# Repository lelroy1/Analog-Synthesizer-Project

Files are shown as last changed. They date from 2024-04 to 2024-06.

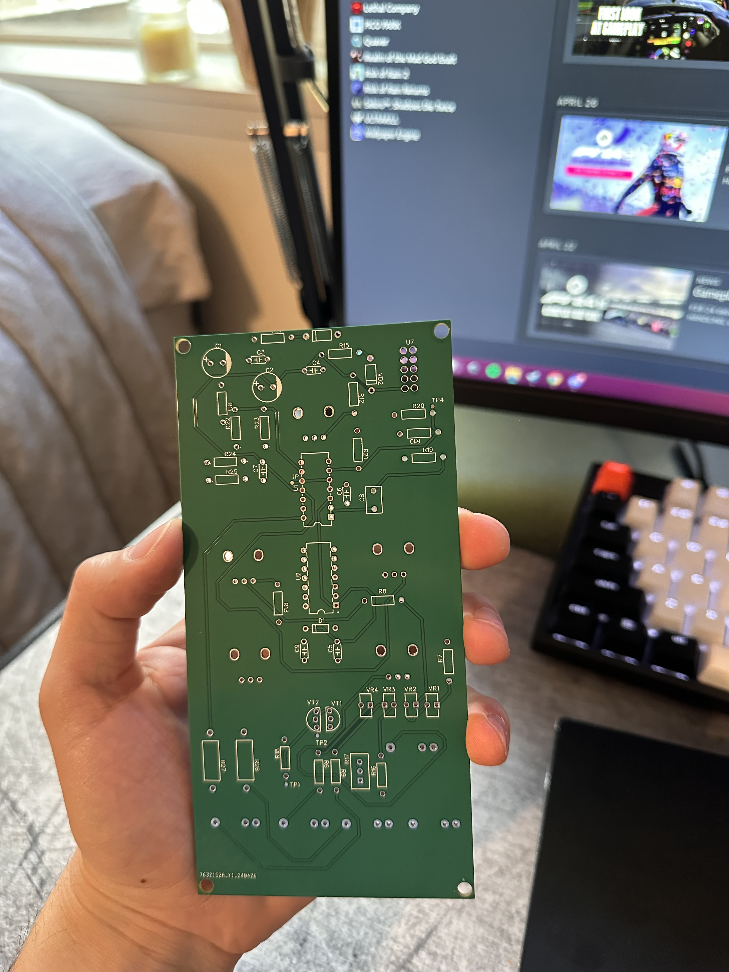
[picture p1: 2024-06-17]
VCO/PCB before Soldering back.JPG

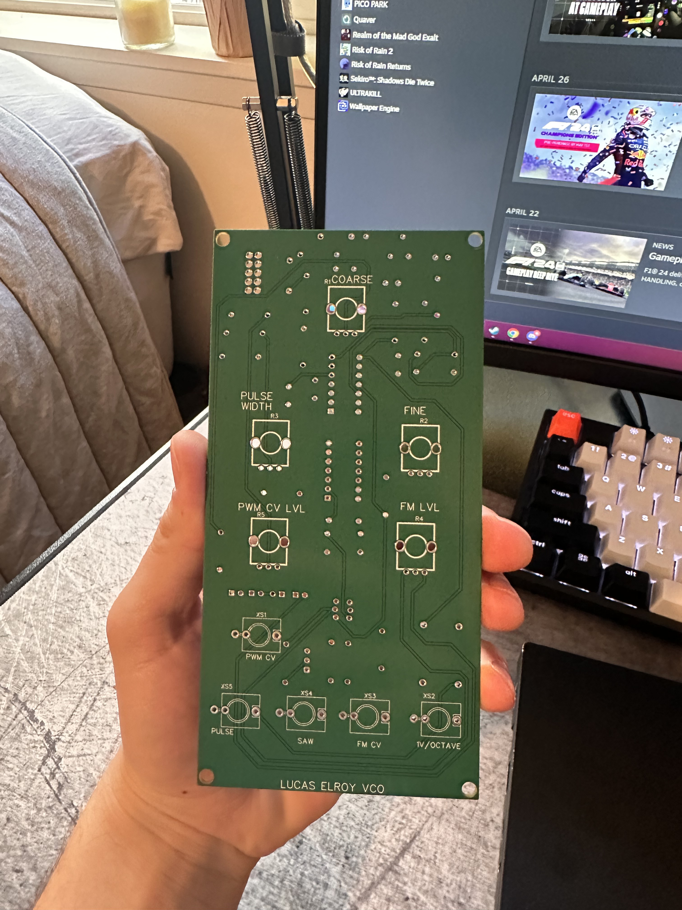
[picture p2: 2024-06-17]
VCO/PCB before Soldering.JPG

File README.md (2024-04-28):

# Analog-Synthesizer-Project
This repository contains all the work I've done to design my own analog synthesizer. The ultimate goal of this project is to design the analog circuits for a VCO (voltage controlled oscilator), VCA (voltage controlled amplifier) and VCF (voltage controlled filter). The design process for each of these components will be detailed here. The basic design flow will be testing and simulating in LTSpice, breadboarding the design, then creating a PCB. Along with this I will be machining cases each of these components and designing a power supply unit for them.

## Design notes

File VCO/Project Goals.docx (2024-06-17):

1. Understand the process of designing PCBs better.
  a. Sourcing correct parts for a design and what facets of a part are important aside from just component resistance/capacitance
  b. Where to place components for performance and correctness
2. Learn more about analog design
  a. Adding some sort of feature to the design
  b. Understanding each part of the design
3. Investigate a potential passion I may have (Music related Electrical Engineering)
  a. Analyze if this is something to continue pursuing after completion.

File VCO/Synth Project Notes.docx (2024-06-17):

4/6 - Today I did a basic creation of the schematic of the VCO. I’m worried about how to simulate it and I will likely need to go through and insert all the part numbers. I need to find these on a website to source all of them from. Make 100% sure everything matches.

Next Steps: Formulate some questions for Robert (peer reviewer) about simulating

4/7 - Today I redid the circuit by remodeling the components to spice models that way I can simulate it. Tomorrow I should look into actually simulating it which might require looking into those youtube videos a lot more so I understand what to test.

4/9 - I’m pretty stuck on simulating the reverse sawtooth oscillator core. I can’t figure out how to get the inverter to oscillate. Tomorrow you should look into downloading the CD40106 model onto LTspice and get it to actually work.

4/10 - I got the basic spice simulation working for the oscillator core. I also did some research into sourcing the parts for the PCB. I need to make sure Robert checks these. Tomorrow I will finish sourcing these parts and maybe look into simulating the whole circuit just to verifying I didn’t mess up routing.

4/11 - I need to find a way to put the 10 pin male connector on the PCB. I was also thinking that I need to spend significantly more time understanding the circuit I am creating. That way I learn more and get more confidence with the creation. There is also the idea of adding some sort of difference between my design and the mortiz klein one. Change capacitor footprint.

4/12 - Does the pin which is negative 12 matter vs positive 12 when it comes to plugging in the power supply? My guess is no.

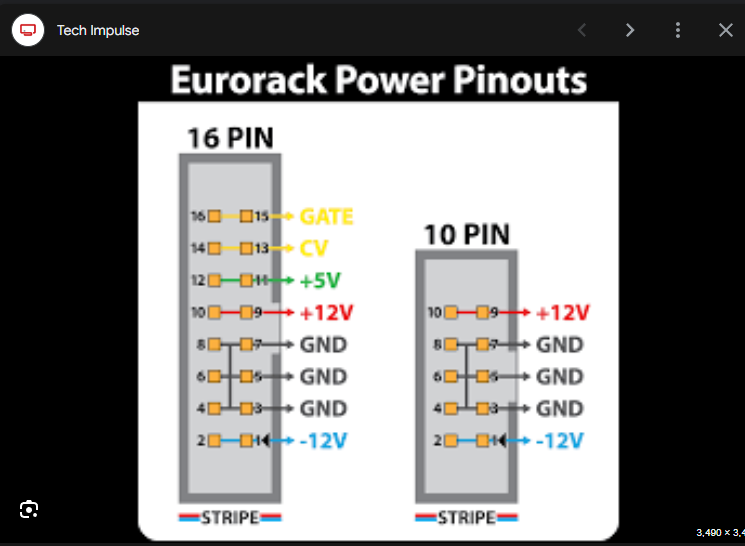
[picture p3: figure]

https://www.google.com/search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

4/14 - I spent some time today just understanding PCB design stuff and watching videos on it. I am torn about whether I want to go through and simulate the entirety of the design to better understand it. If I do choose to go down that route it will likely take up the next month of my time and I’m being lazy by not wanting to do that. So, let's discuss what my process should be. I like the idea of potentially building the circuit alongside the designs and testing each phase incrementally to understand the entirety of the circuit step by step. So I guess my next step now would be to model the voltage controlled resistor with the BJTs.

4/18 - Should I have both a +12V and -12V plane? Some pins on PCB have no lines referencing where they should be routed to is this do I route them to the correct reference anyway? Should I wire together all +12, -12, GND references on PSU 10 pin connector?

4/19 - route tp on top and bottom

4/21 -

- there needs to be a copper pour on the same layer as the traces, so you dont have large amounts of empty space. The manufacturer may have to leave it in the etch longer to make larger areas dissolve, though this isn't much of a problem in modern pcb manufacturing. you should make this a ground layer, and add test points to it on the outside, so that you can have many easy access points to ground when probing for testing. you can even buy test point clip parts. one we like is 5001 from keystone.

Currently having a problem with the DRC related to the ground holes in the corners.

4/23 - still having the problem with creating mounting holes. I’m also now concerned with the PSU. I did not realize it would be $80 so now I’m considering powering the whole system with 2 9 volt batteries or a bench power supply ~$50. For now I will just use the power supplies in the tectronics lab.

4/24 - currently in the process of simulating everything from the youtube videos.

4/28 - I need to go into the techtronics lab to breadboard and test the circuit.

VCO - voltage controlled oscillator.

Needs to be tuned with a pitch knob

This seems to be the basis of all oscillation in a synth. Here is the basic design of a sawtooth oscillator:

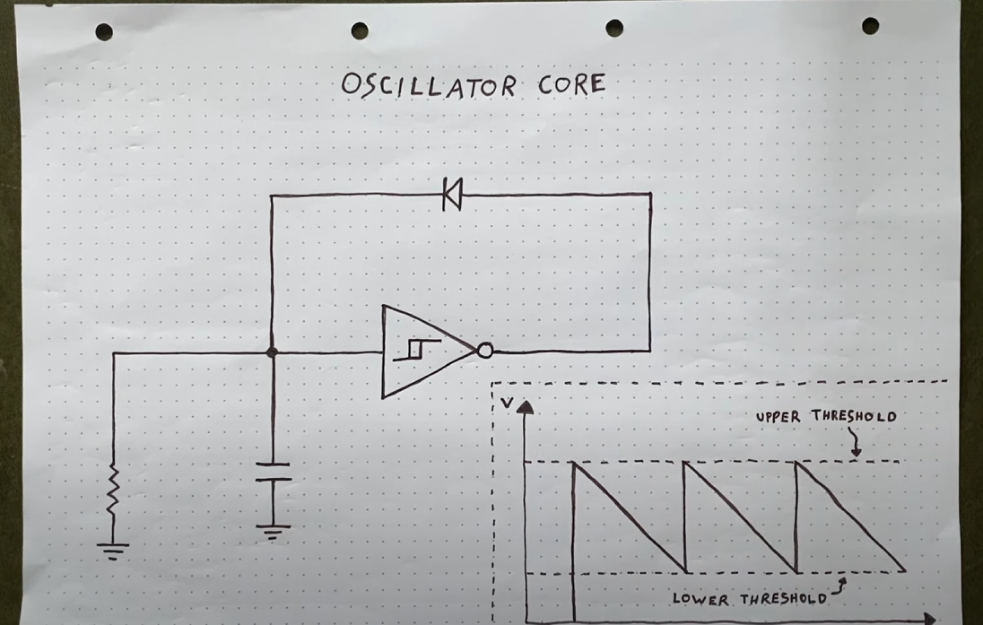
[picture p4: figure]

The capacitor rate of discharge through the parallel resistor is what determines the frequency of the output wave.

Capacitor size: as it raises the frequency lowers

Not useful since it changes the shape of the wave since the charge of the capacitor isn’t instant and takes a non-zero amount of time.

Resistor Value: as it raises the frequency lowers

Use a NPN bipolar junction transistor - ability to open to different degrees.

We need the resistance value to increase exponentially because that is how notes work with frequency.

VCF - voltage controlled filter

Low pass type thing

VCA - voltage controlled amplifier

Uses an envelope generator or LFO as input

LFO - low frequency oscillator

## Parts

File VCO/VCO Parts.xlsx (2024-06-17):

PART | Number | Model Number | Source
1M Resistor | 2 |  | https://www.digikey.com/en/products/detail/stackpole-electronics-inc/RNV14FAL1M00/2665258
100k Resistor | 9 |  | https://www.digikey.com/en/products/detail/yageo/MFR-25FRF52-100K/14630
68k Resistor | 2 |  | https://www.digikey.com/en/products/detail/yageo/MFR-25FTE52-68K/9140353
47k Resistor | 1 |  | https://www.digikey.com/en/products/detail/yageo/MFR-25FTE52-47K/9140226
33k Resistor | 1 |  | https://www.digikey.com/en/products/detail/yageo/MFR-25FTE52-33K/9140102
14k Resistor | 1 |  | https://www.digikey.com/en/products/detail/yageo/MFR-25FBF52-14K/13246
1k5 Resistor | 1 |  | https://www.digikey.com/en/products/detail/yageo/MFR-25FRF52-1K5/14908
1k Resistor | 2 |  | https://www.digikey.com/en/products/detail/stackpole-electronics-inc/RSF1JT1K00/1686160
10 Resistor | 2 |  | https://www.digikey.com/en/products/detail/vishay-beyschlag-draloric-bc-components/AC03000001009JACCS/4093333
10k Thermistor | 4 |  | https://www.digikey.com/en/products/detail/vishay-beyschlag-draloric-bc-components/NTCLE100E3103HB0/769421
47 uF electrolytic capacitor | 2 | EEU-FR1J470 | https://www.digikey.com/en/products/detail/panasonic-electronic-components/EEU-FR1J470/3072280
1 uF 1J/film capacitor | 1 | B32529C0105J000 | https://www.digikey.com/en/products/detail/epcos-tdk-electronics/B32529C0105J000/592697
100 nF (104/ceramic) | 5 | CK05BX104K | https://www.digikey.com/en/products/detail/vishay-beyschlag-draloric-bc-components/K104K10X7RF5UH5/2356754
2.2nF (2n2/film) | 1 |  | https://www.digikey.com/en/products/detail/kemet/R82EC2220DQ50J/1930805
1N4148 signal diode | 1 |  | https://www.digikey.com/en/products/detail/onsemi/1N4148/458603
SB150^2 schottky diode | 2 |  | https://www.digikey.com/en/products/detail/vishay-general-semiconductor-diodes-division/SB150-E3-54/604911
BC548 NPN Transistor | 1 |  | https://www.digikey.com/en/products/detail/onsemi/BC548CTA/975552
BC558 PNP Transistor | 1 |  | https://www.mouser.com/ProductDetail/Diotec-Semiconductor/BC558A?qs=OlC7AqGiEDmcth9qWeGNYA%3D%3D&mgh=1
1k w102 trimmer potentiometer | 1 |  | https://www.digikey.com/en/products/detail/bourns-inc/PV36W102C01B00/666501
100k B104 potentiometer | 3 | PTV09A-4015F-B104 | https://www.digikey.com/en/products/detail/bourns-inc/PTV09A-4015F-B104/3781114
250k B254 potentiometer | 1 | PTV09A-2015S-B254 | https://www.digikey.com/en/products/detail/bourns-inc/PTV09A-2015S-B254/4699517
1M B105 potentiometer | 1 | PTV09A-4020F-B105 | https://www.digikey.com/en/products/detail/bourns-inc/PTV09A-4020F-B105/4699522
Switched mono black jack sockets | 5 | WQP-PJ301M-12 | https://store.synthrotek.com/thonkiconn_mono_jack
TL074 quad op amp IC | 1 | TL074CN | https://www.mouser.com/ProductDetail/Texas-Instruments/TL074CN?qs=AMJt07B76uv7dLYnj7iLiQ%3D%3D
CD40106 hex schmitt trigger inverter IC | 1 |  | https://www.mouser.com/ProductDetail/Texas-Instruments/CD40106BEE4?qs=UFeyouyReuHWFIMn%2FS5lqw%3D%3D
Power supply socket | 1 | Pitch : 2.54mm | https://www.amazon.com/Uxcell-a14112600ux0299-2-54mm-Straight-Connector/dp/B00VGDRBXY
PSU | 1 |  | https://tiptopaudio.com/uzeus/
Ribbon cable from VCO to PSU | 1 |  | https://store.synthrotek.com/keyed_16-pin_to_10-pin_eurorack_modular_power_cable
SOIC Sockets | 1 |  | https://www.amazon.com/SCS-14-Socket-Stamped-Narrow-Width/dp/B019X1TM5U
Speaker for testing |  |  | https://www.amazon.com/Portable-Mini-Capsule-Speaker-System/dp/B007OYAVLI
cord to connect to amp |  |  | https://www.amazon.com/Hosa-CMP-303-Mono-Interconnect-Cable/dp/B000068O3G

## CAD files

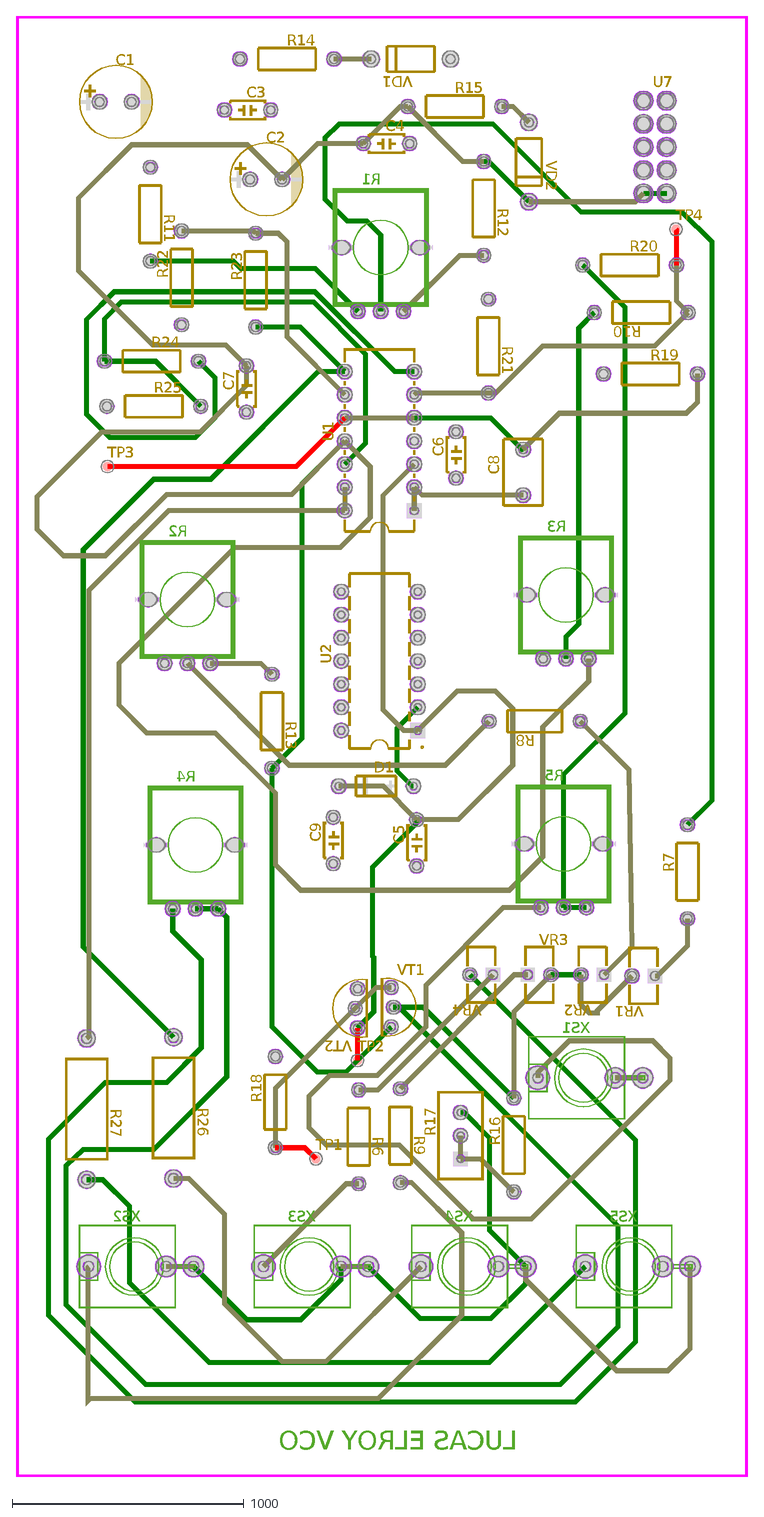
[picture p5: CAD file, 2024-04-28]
VCO/VCO_PCB.dxf
LUCAS ELROY VCO
R1
R2
R3
R4
R5
XS1
XS2
XS3
XS4
XS5
D1
R23
C1
C2
C3
C4
C5
C6
C7
C9
C8
VD1
VD2
R6
R7
R9
R10
R11
R12
R13
R14
R15
R16
R19
R20
R21
R22
R24
R25
R8
R18
R17
R26
R27
TP1
TP2
TP3
TP4
U2
U7
VR1
VR2
VR3
VR4
VT1
VT2
U1

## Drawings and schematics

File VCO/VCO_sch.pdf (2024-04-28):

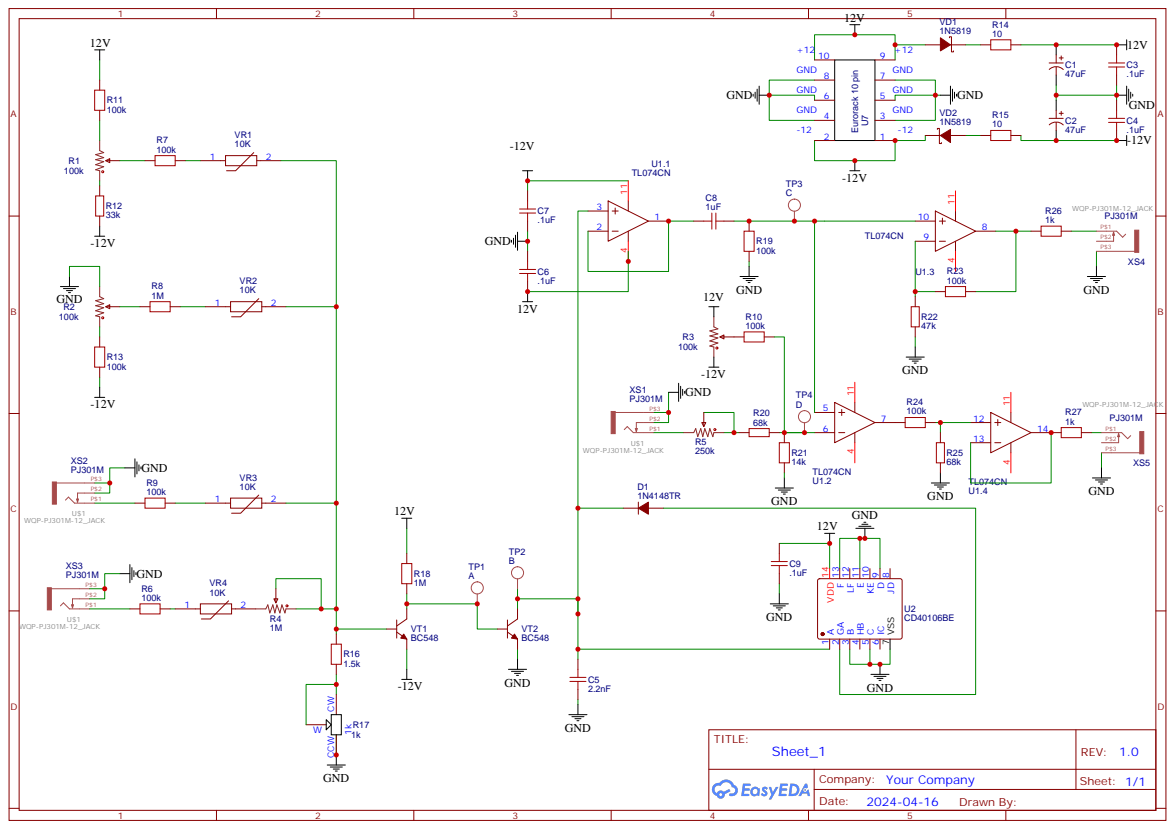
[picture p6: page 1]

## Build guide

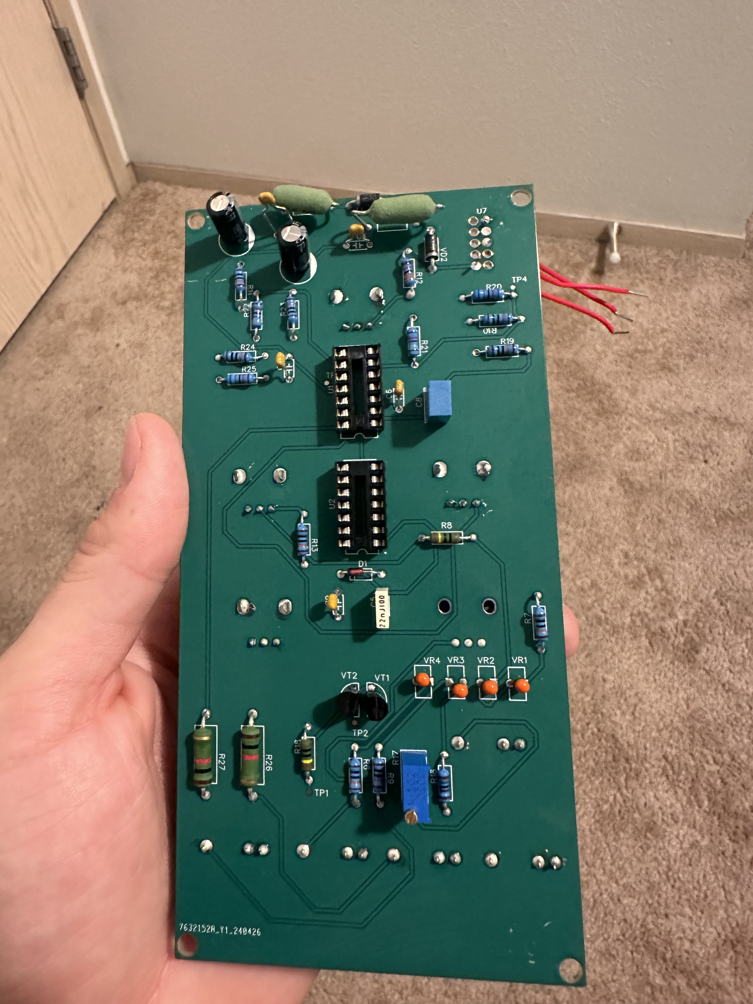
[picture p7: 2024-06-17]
VCO/PCB after Soldering back.JPG

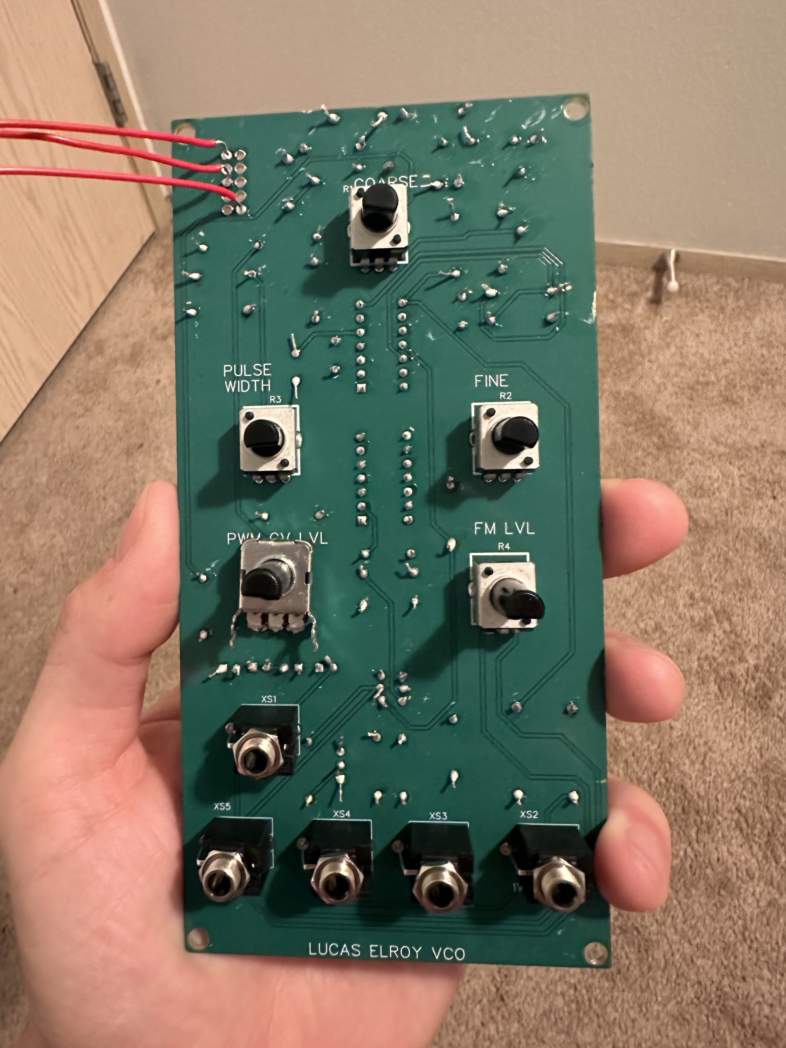
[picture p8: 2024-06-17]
VCO/PCB after Soldering.JPG

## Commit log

2024-06-17 Rename PCB after Soldering (1).JPG to PCB after Soldering.JPG
2024-06-17 Rename PCB after Soldering back (1).JPG to PCB after Soldering back.JPG
2024-06-17 Rename VCO Parts (1).xlsx to VCO Parts.xlsx
    [VCO Parts.xlsx]
